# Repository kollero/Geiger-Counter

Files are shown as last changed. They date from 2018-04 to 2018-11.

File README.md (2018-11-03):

# Geiger-counter version 4 C rev

Uses wireless charger so it can be made waterproof. PCB is also narrower and components are more tightly packed. New STL files are needed. 

With 2x sbm-20 tubes, 1.3" Oled display (7pins), Single button on/ (hold) off control (with led), wireless charging,
Atmega328p, only exotic component is mcp73871 (lipo charger IC). 

Display shows time the device has been on (up to 999hours), battery charge after 5 seconds running, 5 second mean of radiation in the middle, current high voltage running to the tubes, and mean value of radiation since the device has been turned on. When detection is made the on/off buttons led is flashed and a chirp is generated. 

5v to 400v boost features IPD90R1k2C3 mosfet, runs at ~22kHz (outside human hearing),
1mH (ELL8TP102MB) inductor is barely enough for this frequency (mainly ESR), also used tantalum capacitors have high ESR, PWM is
PID controlled using atmega328p's 16bit counter.

single ~5000mAh lipo cell, 806090 in size.

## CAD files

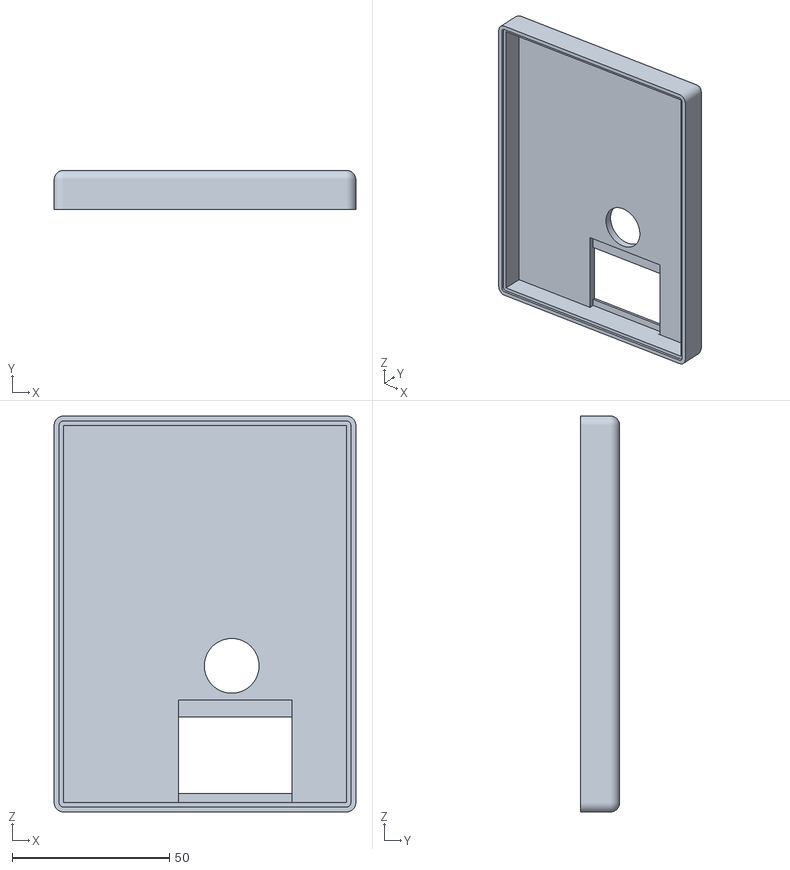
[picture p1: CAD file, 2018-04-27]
STL/1st_gen_top.STL
96.0 x 12.5 x 126.0

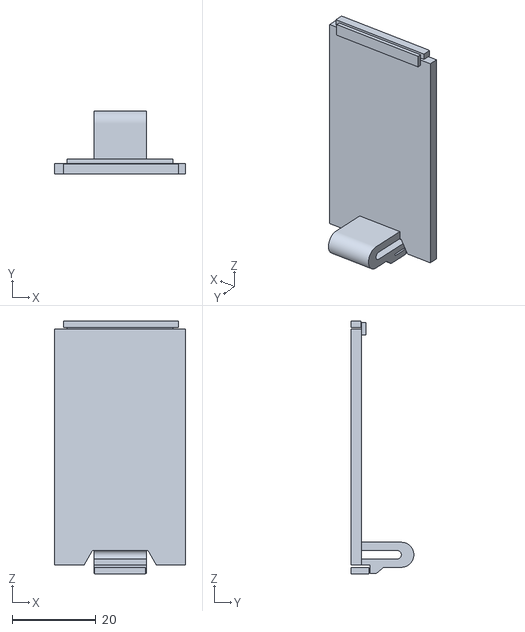
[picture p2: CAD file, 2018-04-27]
STL/cover.STL
31.4 x 15.0 x 60.5

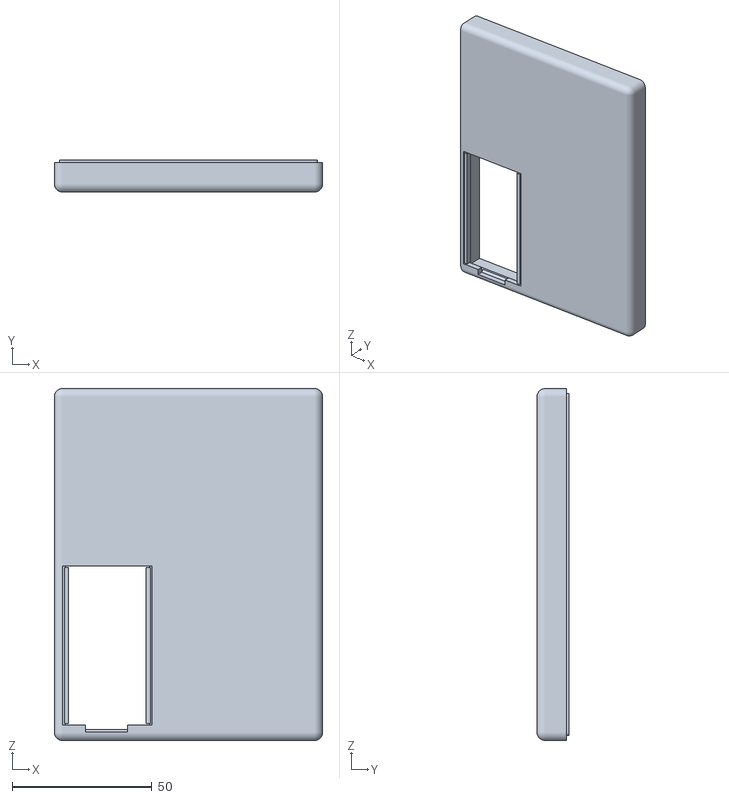
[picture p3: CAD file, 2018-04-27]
STL/1st_gen_bot.STL
96.1 x 11.5 x 126.0

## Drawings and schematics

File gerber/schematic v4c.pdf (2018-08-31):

D

6 | 5 | 4 | 3 | 2 | 1

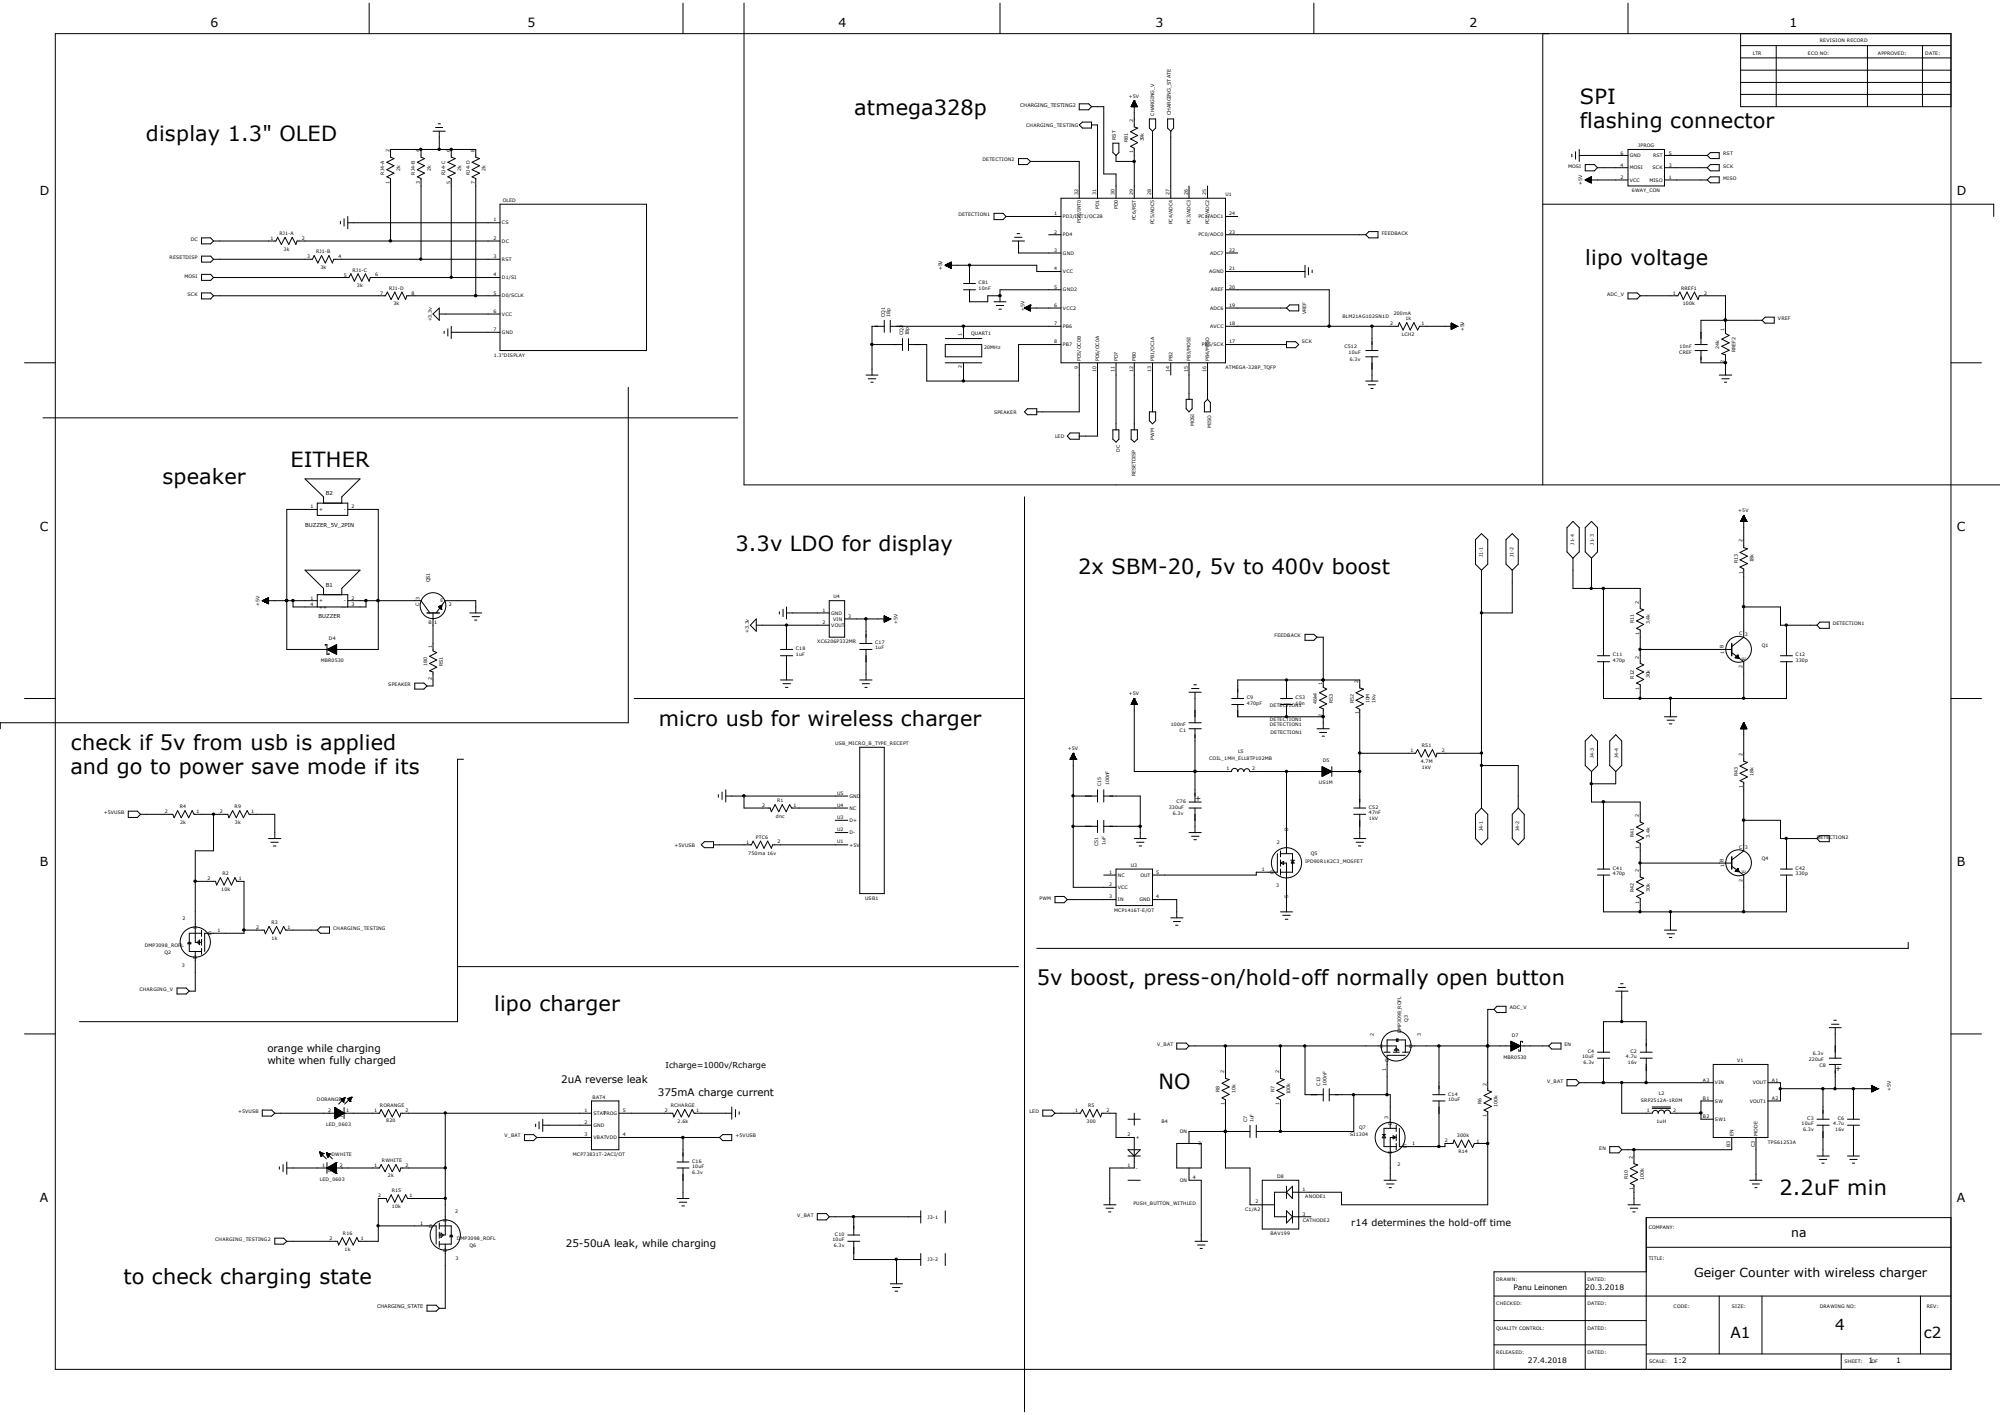
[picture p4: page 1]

display 1.3" OLED | CHARGING_TESTING2 CHARGING_STATE | JPROG | REVISION RECORD

LTR | ECO NO: | APPROVED: | DATE:

24 PC1/ADC1 ²⁵ PC2/ADC2 26 PC3/ADC3 27 PC4/ADC4 28 PC5/ADC5 29 PC6/RST 30 PD⁰ ³¹ PD¹ ³² PD²/INT0

micro usb for wireless charger

check if 5v from usb is applied
and go to power save mode if its

5v boost, press-on/hold-off normally open button

orange while charging
white when fully charged

r14 determines the hold-off time

to check charging state

TITLE:
Geiger Counter with wireless charger

DRAWN: Panu Leinonen | DATED: 20.3.2018
CHECKED: | DATED: | CODE: | SIZE: A1 | DRAWING NO: 4 | REV: c2

QUALITY CONTROL: | DATED:

RELEASED: 27.4.2018 | DATED:

SCALE: 1:2 | SHEET: 1 1 OF

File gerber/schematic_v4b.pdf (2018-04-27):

D

6 | 5 | 4 | 3 | 2 | 1

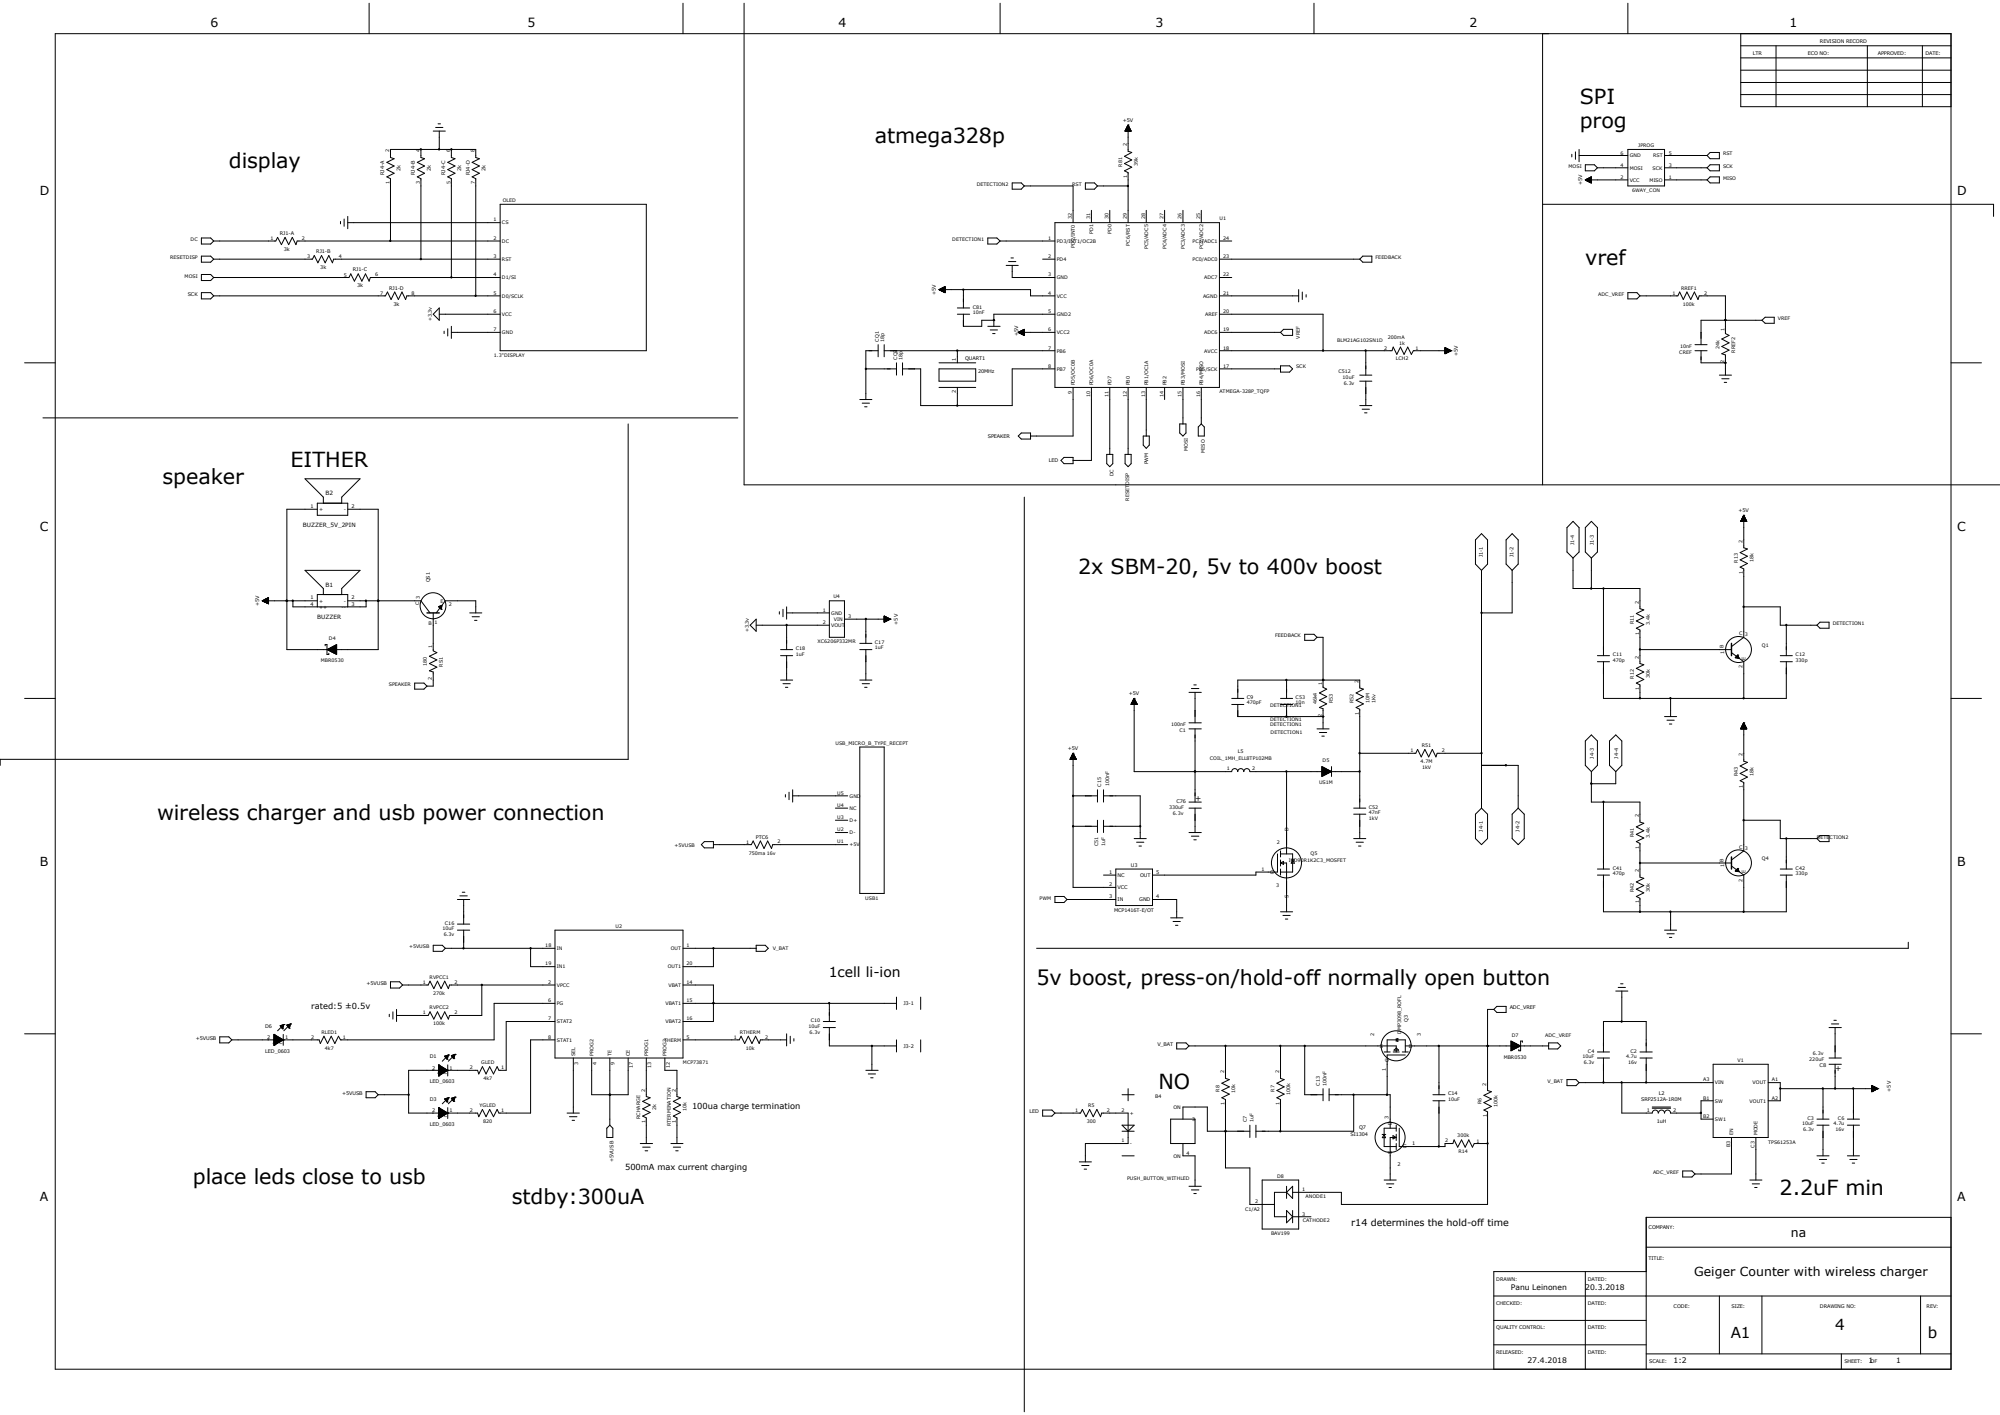
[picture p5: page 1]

DETECTION2 RST | JPROG | REVISION RECORD

LTR | ECO NO: | APPROVED: | DATE:

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

wireless charger and usb power connection

5v boost, press-on/hold-off normally open button

place leds close to usb

r14 determines the hold-off time

Geiger Counter with wireless charger

DRAWN: Panu Leinonen | DATED: 20.3.2018
CHECKED: | DATED: | CODE: | SIZE: A1 | DRAWING NO: 4 | REV: b

QUALITY CONTROL: | DATED:

RELEASED: 27.4.2018 | DATED:

SCALE: 1:2 | SHEET: 1 1 OF

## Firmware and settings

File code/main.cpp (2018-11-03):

/*
 * geigerV14.cpp
 *
 * Created: 20.9.2018 20.53.21
 * Author : kei
 */ 

#define OVERSAMPLING 3
#define I_memory 40 //samples

#define P_val 10
#define I_val 3
#define D_val 6

#include <stdlib.h>
#include <math.h>
#include <stdio.h>
#include <avr/pgmspace.h>
#include <avr/interrupt.h>
#include <avr/wdt.h>
#include <avr/io.h>
#include <util/delay.h>
#include <stdint.h>
#include <stdbool.h>

#include "u8g.h"
u8g_t u8g;



//single sbm-20
double tube1 = 0.344827586207;
//dual sbm-20
double tube2 = 0.172413793104;

double input_voltage_calc = 0.00647; //(10k/8k)*(5v/1024)=0.00610351
double battery_voltage_lvl_calc=0.02576; //(124/24)*(5v/1024)=

//sbm-20 recommended running voltage
double target_voltage=400.0;  //~400v calculated output from resistors


/************************************************************************************************************************************************/
/* Global Objects                                                       																		*/
/************************************************************************************************************************************************/
volatile int32_t    mean_I_err[I_memory],
					PID=0,
					err=0,
					err_old=0,
					mean_I_error=0.0,
					I_err=0.0,
					P_err=0,
					D_err=0;

volatile uint32_t	timer_1s=0,		//these are test counters
					timer_1min=0,
					timer_1h=0,
					geiger_pulse1=0,
					geiger_pulses1=0,
					geiger_pulse2=0,
					geiger_pulses2=0,
					geiger_cps=0,
					geiger_cps2=0,
					total_time_in_seconds=0;

volatile int16_t	duty=0, //initial number
					testing=0,
					fb_voltage=0,
					duty_max=600; 			  //maximum duty cycle/ICR1	39%

volatile uint16_t	timer_seconds=0,	//these house the real time values from when the device was started
					timer_minutes=0,
					timer_hours=0,
					totalnum=0,
					totalnum2=0,
					volt_value=0,
					duty_change_counter=0;
					
volatile bool		first_minute_passed = 0,
					refresh_display=1,
					high_voltage_duty_change=0,
					check_pulses=0,
					v_inputted=0,
					charging=0,
					first_min = 0,
					now=0;
					
bool				cmd_pulse=0,
					setnewhv=0,
					led=0,
					batterylevelcheck=0,
					timernow=0,
					dos_trig_2=0,
					dos_trig=0,
					battery_voltage_check_first_time=1,
					detected_as_broken=0;					
						
uint16_t 			battery_voltage_lvl_ADC=0,
					broken_counter=0;
					
double				actual_cps=0.0,
					actual_cps2=0.0,
					HV_vol=0.0,
					dosage=0.0,
					dosage_1=0.0,
					total_dose=0.0,
					dosage_total=0.0,
					bat=0.0,
					charging_voltage=0.0,
					battery_voltage_lvl= 0.0,	
 					usv=0.0,
					usv_1=0.0,
					actual_cps3=0,
					usv3=0;				
					
uint32_t			totalinmin[60],
					totalinmin2[30];
			
uint16_t xx=120, yy=35, y_start=14;

//chars arrays for printing
char battery[10]={0,0,0,0,0,0,0,0,0,0};	
char secs[10]={0,0,0,0,0,0,0,0,0,0};	
char mins[10]={0,0,0,0,0,0,0,0,0,0};	
char hours[10]={0,0,0,0,0,0,0,0,0,0};	
char usvs[10]={0,0,0,0,0,0,0,0,0,0};	
char HV[10]={0,0,0,0,0,0,0,0,0,0};	
char DOS[10]={0,0,0,0,0,0,0,0,0,0};	
char CHAR_VOLT[10]={0,0,0,0,0,0,0,0,0,0};	
char string_battery_ADC[10]={0,0,0,0,0,0,0,0,0,0};	
char string_bat_percent[10]={0,0,0,0,0,0,0,0,0,0};	

/************************************************************************************************************************************************/
/* Global Objects end                                                       																	*/
/************************************************************************************************************************************************/

#include "lipo.h"
#include "functions.cpp"
#include "pitches.h"
#include "test_sounds.h"

void u8g_setup(void)
{
	
	// SCK: PORTB, Bit 5 --> PN(1,5)
	// MOSI: PORTB, Bit 3 --> PN(1,3)
	// CS: PORTD, Bit 6 --> PN(3,6)
	// A0: PORTD, Bit 7 --> PN(3,7) //DC!!
	// RST: PB0,  --> PN(1,0)
	// Arguments for u8g_InitHWSPI are: CS, A0, Reset
	
	//u8g_InitHWSPI(&u8g, &u8g_dev_ssd1306_128x64_hw_spi, U8G_PIN_NONE,PN(3,7), PN(1,0));
	
	//these work
	u8g_InitHWSPI(&u8g, &u8g_dev_sh1106_128x64_hw_spi,U8G_PIN_NONE,PN(3,7), PN(1,0));
	u8g_SetRot180(&u8g); //flip screen, if required
	
	//u8g_InitHWSPI(&u8g, &u8g_dev_ssd1309_128x64_hw_spi, U8G_PIN_NONE,PN(3,7), U8G_PIN_NONE);
	//u8g_SetRot180(&u8g); //flip screen, if required
	//u8g_SetColorIndex(&u8g, 1);
	
}
void system_setup() {
	
	//pb0=rst disp, pb1 pwm, pb3 mosi, pb5 sck
	DDRB = (1<<PORTB0)|(1<<PORTB1)|(1<<PORTB3)|(1<<PORTB5);
	PORTB =0x01;
	//pc0 feedback
	DDRC =0x00;
	PORTC =0x00;
	//pd1=input v (int),pd2 and pd3 tubes (extint) , pd5 speaker, pd6 led, pd7 dc 
	DDRD = (1<<PORTD5)|(1<<PORTD6)|(1<<PORTD7);
	PORTD =(1<<PORTD6);
	
	//adc set up
	//ADMUX adlar=0, mux 0000 HV-feedback, mux 0110 battery voltage feedback, input V adc5 0101
	ADMUX=(1<<REFS0);
	ADCSRA=(1<<ADEN)|(1<<ADSC)|(1<<ADPS2)|(1<<ADPS1)|(1<<ADPS0); //with 128 clk division
	
	//PWM
	//fast PWM, non-inverting mode set, 16bit timer
	ICR1=800; //@25kHz top
	OCR1A = 0; //initial duty cycle
	TCCR1A = (1<<COM1A1)|(1<<WGM11); //ICR1 selected as top value
	TCCR1B =(1<<WGM13)|(1<<WGM12)|(1<<CS10);
	TIMSK1 =(1<<OCIE1A);

	//external interrupts
	EICRA=(1<<ISC11)|(1<<ISC01); //falling edges on int1 (pd3) and int0 (pd2)
	EIMSK=(1<<INT1)|(1<<INT0); //mask register
	EIFR=(1<<INTF1)|(1<<INTF0); //clear interrupt flags

	//PCint interrupts
	PCICR=(1<<PCIE2)|(1<<PCIE1);
	PCMSK2=(1<<PCINT17); //PD1
	//PCMSK1=(1<<PCINT12); //PC4
	
	//timer 2 control 8 bit
	//output is 20MHz/(256*125)=1.6ms tick
	OCR2A = 124; //runs to value 0:124, to get exact ms
	TCCR2A = (1<<WGM21);
	TCCR2B =(1<<FOC2A)|(1<<CS22)|(1<<CS21); //force compare match A, prescaler to 256
	TIMSK2= (1<<OCIE2A); //masked compare match A
	
	/*
	//chirp or music from timer 0 B output
	OCR0A =255; //max value
	OCR0B=0; //initial duty cycle
	TCCR0A = (1<<COM0B1)|(1<<WGM00); //phase correct  pwm   |(1<<WGM01)
	TCCR0B =(1<<WGM02)|(1<<CS02);// 256 prescaler (must be same as timer 2)
	//TIMSK0=(1<<OCIE0B); //compare match B interrupt
	*/

}



int main(void)
{
	//delay_ms(1000);
	delay_ms(300);
	//zero arrays
	for (int i=0;i< I_memory-1;i++){
		mean_I_err[i]=(int32_t)0.0;
	}
	for (int i = 0; i < 60; i++ ) {
		 totalinmin[i] = 0;
	}
	
	delay_ms(200);
	system_setup();
	u8g_setup();
	//delay_ms(200);
	LCD_clear();
	delay_ms(200);
	
	if(VOLTAGE_APPLIED_PIN){
		v_inputted=1;
		LEDoff;
	}
	/*if(CHARGING_STATE_PIN){
		charging=1;
		LEDoff;
	}*/
	
	//check_battery_voltage();
	
	//cli();
	sei(); //enable interrupts
	
    while (1) 
    {
		if(high_voltage_duty_change){
			high_voltage_duty_change=0;
			high_voltage_duty();
		}
		
		if(check_pulses){
			check_pulses=0;
			/*
			totalinmin[59]=geiger_pulses1+geiger_pulses2; //collisions per second
			
			for (int k = 0; k <= 58; k++)
			{
				totalinmin[k]=totalinmin[k+1];
			}

			for(int k = 59; k >= 0; k--)
			{
				totalnum=totalnum+totalinmin[k];
			}
			*/
			
			
			totalnum+=geiger_pulses1+geiger_pulses2;
			geiger_pulses1=0;
			geiger_pulses2=0;
			
		
			geiger_cps2=totalnum;
			totalnum=0;
			actual_cps2=((geiger_cps2*1000)/(1000-(geiger_cps2*0.190)));
			//total dosage calculation
			dosage_total+=actual_cps2*tube2;
			//174.46 CPM/uSv/hr)-> (cp_total/348.92)((usv/hr)),((c/m)/hr=(1/60)/1)
			//1/(348.92*60)=0.0000477664412091
		
			//dosage=(double)(dosage_total/60);
			//if(first_minute_passed == 0) {
			//	dosage=(double)((dosage_total*60)/timer_seconds);
			//}
			
			total_time_in_seconds=timer_seconds+60*timer_minutes+360*timer_hours;
			dosage=(double)(dosage_total/total_time_in_seconds);
		
			testing++;
			if (testing>=5) //once every 5 seconds
			{
			
				totalnum2=0;
				for(int k = 59; k >= 55; k--)
				{
					totalnum2+=totalinmin[k];	
				}
			
				totalinmin2[29]=totalnum2; //collisions per second
			
				for (int k = 0; k <= 28; k++)
				{
					totalinmin2[k]=totalinmin2[k+1];
				}
			
				geiger_cps=geiger_pulse1+geiger_pulse2; //collisions per second
				actual_cps=(long double)(geiger_cps/(1000-(geiger_cps*0.190)));
				//actual_cps=(float)(geiger_cps/(1-(geiger_cps*0.000190)));
				//190us dead time on SBM-20 before new detection can be made
				//now we have Collisions Per Second as float
				usv=(long double)((tube2*actual_cps)/testing); //174.46 CPM/uSv/hr
				///174.46 CPM/uSv/hr /60)=2.9-> 1/2.9=0.344 usv/hr
				// close to the average of SBM-20, Co60 and Ra226 sensitivity
				// dosage is now in usv/hr (micro)
				//usv=(long double)usv*1000;
				
				if(!detected_as_broken && ((geiger_pulse1 == 0 && geiger_pulse2 !=0) || (geiger_pulse1 != 0 && geiger_pulse2 ==0))){
					broken_counter++;
				}
				else if(!detected_as_broken && geiger_pulse1 !=0 && geiger_pulse2 !=0){
					broken_counter=0;
				}
				if(broken_counter>=10 && !detected_as_broken){
					broken_counter=0;
					//a tube is broken
					tube2=tube1;
					detected_as_broken=1;					
				}
				
				geiger_pulse1=0;			//reset collision counter/
				geiger_pulse2=0;
				testing=0;
				battery_voltage_check_first_time=0;
			}
		}
		if(batterylevelcheck || (battery_voltage_check_first_time && testing>=4))
		{
			check_battery_voltage();
			//bat=(float)0.0255*battery_voltage_lvl; //battery voltage level if resistors have low % tolerances
			//((2.4k+9.91k)/2.4k)*1024/5
			batterylevelcheck=0;
		}
			
		if (led)
		{
			int gah=1;
			int test=15;
			int microtest=90;
			LEDon;
			led=0;
			
			//main chirp
			while(!led && gah <= test){
				BUZon;
				//delay_ms(1);
				//delay_ms(gah);
				delay_us(microtest);
				BUZoff;
				//delay_us(105);
				delay_us(microtest-gah*7);
				gah++;
			}
			gah=1;
			//trailing edge
			while(!led && gah <= test*2){
				BUZon;
				//delay_ms(1);
				//delay_ms(gah);
				delay_us(microtest-gah*8);
				BUZoff;
				//delay_us(105);
				delay_us(microtest);
				gah++;
			}
			LEDoff;
			
		}
		
		if(refresh_display){
			refresh_display=0;
			if(v_inputted){
				LEDoff;
				check_input_voltage();
				check_battery_voltage();
			}
			
			display_draw();
		}
		
    }
}

ISR(TIMER2_COMPA_vect) { //interrupts every 1.6ms
	timer_1s++;
	//zero the timer if 1 second has been reached
	if(timer_1s >= 625)		//625*1.6ms=1s
	{
		timer_seconds++; //increase if under 59 sec
		refresh_display=1; //1 second has passed time to refresh display
		check_pulses=1;
		timer_1s=0;
		if(timer_seconds > 59)
		{
			timer_seconds=0; //zero if
			first_minute_passed=1;
			batterylevelcheck=1;
			timer_minutes++; //increase if under 59 min
			if(timer_minutes > 59)
			{
				timer_minutes=0; //zero if
				timer_hours++;
				if(timer_hours > 998) // no more than 2 digits for hours in display
				{
					timer_hours=0; //zero the timer
				}
				//1hour reached
				timer_1h=0;
			}
			timer_1h++;
		}
	}
}

//high voltage PWM interrupt 
ISR(TIMER1_COMPA_vect){	
	high_voltage_duty_change=1;
	//high_voltage_duty();
}


// external interrupts, falling edges on either
// we have a top limit of 2^32-1 pulses.
ISR (INT0_vect) {
	geiger_pulse1++;
	geiger_pulses1++;
	led=1;
}
ISR (INT1_vect) {
	geiger_pulse2++;
	geiger_pulses2++;
	led=1;
}

//5v applied to charging port
ISR (PCINT2_vect){
	if(VOLTAGE_APPLIED_PIN){
		v_inputted=1;
		battery_voltage_check_first_time=0;
	}
	else{
		v_inputted=0;
		battery_voltage_check_first_time=1;
		testing=0;
	}	
}
/*
//charging
ISR (	PCINT1_vect){
	if(CHARGING_STATE_PIN){
		charging=1;
	}
	else{
		charging=0;
	}
	
	
}*/

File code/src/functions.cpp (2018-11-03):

typedef struct{
	unsigned int bit0:1;
	unsigned int bit1:1;
	unsigned int bit2:1;
	unsigned int bit3:1;
	unsigned int bit4:1;
	unsigned int bit5:1;
	unsigned int bit6:1;
	unsigned int bit7:1;
} _io_reg;
#define REGISTER_BIT(rg,bt) ((volatile _io_reg*)&rg)->bit##bt

#define	LED_PORT REGISTER_BIT(PORTD,6)
#define LEDon LED_PORT = 1
#define LEDoff LED_PORT = 0

#define	SOUND_PORT REGISTER_BIT(PORTD,5)
#define BUZon SOUND_PORT = 1
#define BUZoff SOUND_PORT = 0

#define	CHARGING_STATE_PIN REGISTER_BIT(PINC,4)

#define	VOLTAGE_APPLIED_PIN REGISTER_BIT(PIND,1)

void high_voltage_duty(){
	duty_change_counter++;
	
	if(duty_change_counter >= 100){ //25kHz/100=250Hz
		duty_change_counter=0;
		ADMUX=0b01000000;
		//_delay_us(1);
		volt_value=0;
		fb_voltage=0;
		while(volt_value < OVERSAMPLING){
			ADCSRA |= (1 << ADSC);	 //start an ADC conversion
			while(ADCSRA & _BV(ADSC));    //wait until conversion is complete
			fb_voltage+=ADC;
			volt_value++;
		}
		fb_voltage=round(fb_voltage/OVERSAMPLING);
		HV_vol=(double)1.05*fb_voltage;
		
		// measured 5v actual vcc and resistor values
		//((fb_voltage*5)*((9680000+46.4E3)/46.4E3))/1024=voltage
		//5*209.620689655=0.977
		
		//PID
		err_old=err;
		err=target_voltage-HV_vol;
		P_err=err; //Proportional is directly the difference times P_val (bang bang value)
		
		mean_I_err[I_memory-1]=(int32_t)err;
		mean_I_error=0;
		for (int i=0;i< I_memory-1;i++){
			mean_I_err[i]=(int32_t)mean_I_err[i+1];
			mean_I_error+=(int32_t)mean_I_err[i];
		}
		mean_I_error+=(int32_t)err;
		I_err=(int32_t)mean_I_error;
		D_err=(int32_t)err-err_old;
		
		PID=(int32_t)P_val*P_err + I_val*I_err + D_val*D_err;
		
		
		if( PID > duty_max )
		{
			PID=duty_max;
		}
		else if(PID < 0){
			PID=0;
		}
		
		if(!v_inputted){
			duty=(uint16_t)PID;
			OCR1A=duty; //OCR1A is 16-bit register and now houses the "right" PWM duty cycle for HV
		}
		else{
			OCR1A=0;
			mean_I_error=0;
		}
		
	}
	
}


void check_battery_voltage(){
	//	battery voltage level check at start
		ADMUX=0b01000110; 			  // muxer to battery voltage feedback
		//SMCR |= (1 << SE);
		//SMCR |= (1 << SM0); //adc-noise reduction sleep mode		
		ADCSRA |= (1 << ADSC);
		//ADCSRA |= ADSC;               // start an ADC conversion
		while(ADCSRA & _BV(ADSC));    // wait until conversion is complete
		//ADCSRA |= ADSC;               // start an ADC conversion
		ADCSRA |= (1<<ADSC);
		while(ADCSRA & _BV(ADSC));    // wait until conversion is complete
		//SMCR |= (0 << SE);			//back from sleep
		battery_voltage_lvl_ADC = ADC;    // save the value to battery_voltage_lvl
		ADMUX=0b01000000; 			  // back to HV feedback
		//ADCSRA |= (1<<ADSC);
		//ADCSRA |= ADSC;               // start an ADC conversion
		//while(ADCSRA & _BV(ADSC));    // wait until conversion is complete
		battery_voltage_lvl=(double)battery_voltage_lvl_ADC*battery_voltage_lvl_calc;	
		//batterylevelcheck=1;
}




// reverses a string 'str' of length 'len'
void reverse(char *str, int len)
{
	int i=0, j=len-1, temp;
	while (i<j)
	{
		temp = str[i];
		str[i] = str[j];
		str[j] = temp;
		i++; j--;
	}
}


/*
// Converts a given integer x to string str[].  d is the number
// of digits required in output. If d is more than the number
// of digits in x, then 0s are added at the beginning.
int intToStr(int x, char str[], int d)
{
	int i = 0;
	while (x)
	{
		str[i++] = (x%10) + '0';
		x = x/10;
	}
	
	// If number of digits required is more, then
	// add 0s at the beginning
	while (i < d)
	str[i++] = '0';
	reverse(str, i);	
	str[i] = '\0';
	return i;
}*/


int  intToStr(int x, char str[], int  d)
{
	int  i = 0;
	while (x)
	{
		str[i++] = (x%10) + '0';
		x = x/10;
	}
	
	// If number of digits required is more, then
	// add 0s at the beginning
	while (i < d)
	str[i++] = '0';
	reverse(str, i);
	str[i] = '\0';
	return i;
}



// Converts a floating point number to string.
void ftoad(long double n, char *res, int afterpoint)
{
	// Extract integer part
	int  ipart = (long double)n*1000;
	
	// Extract floating part
	long double fpart =(long double) ((long double)(n*1000) - (long double)ipart);
	
	// convert integer part to string
	//int i = intToStr(ipart, res, 0);
	uint16_t  i = intToStr(ipart, res, 1); //forces to show 0 at the beginning

	// check for display option after point
	if (afterpoint != 0)
	{
		res[i] = '.';  // add dot
		
		// Get the value of fraction part upto given no.
		// of points after dot. The third parameter is needed
		// to handle cases like 233.007
		fpart = fpart* pow(10, afterpoint);
		
		intToStr((int)fpart, res + i + 1, afterpoint);
	}
}

// Converts a floating point number to string.
void ftoa(float n, char *res, int afterpoint)
{
	// Extract integer part
	int ipart = (int)n;
	
	// Extract floating part
	float fpart =(float) (n - (float)ipart);
	
	// convert integer part to string

	//int i = intToStr(ipart, res, 0);

	int i = intToStr(ipart, res, 1); //forces to show 0 at the beginning

	// check for display option after point
	if (afterpoint != 0)
	{
		res[i] = '.';  // add dot
		
		// Get the value of fraction part upto given no.
		// of points after dot. The third parameter is needed
		// to handle cases like 233.007
		fpart = fpart * pow(10, afterpoint);
		
		intToStr((int)fpart, res + i + 1, afterpoint);
	}
}

void delay_us(int us){
	for (int i=0; i < us; i++){
		_delay_us(1);
	}
}

void delay_ms(int ms){
	for (int i=0; i < ms; i++){
		_delay_ms(1);
	}
}	

void LCD_clear(void)
{	
	u8g_SetDefaultBackgroundColor(&u8g);
	u8g_DrawBox(&u8g,0,0,132,64); //clears the screen
	u8g_SetDefaultForegroundColor(&u8g);
	u8g_SetFont(&u8g, u8g_font_6x10);
	//u8g_DrawBox(&u8g, 5,10,20,10);
	
}

#define battery_x_offset 7

void battery_full_marking(void)
{
	u8g_SetFont(&u8g, u8g_font_7x13);
	u8g_DrawBox(&u8g,66+battery_x_offset,7,2,3);
	u8g_DrawBox(&u8g,68+battery_x_offset,5,11,7);      
}

void battery_80_90_marking(void)
{
	u8g_SetFont(&u8g, u8g_font_7x13);
	u8g_DrawBox(&u8g,66+battery_x_offset,7,2,3);
	u8g_DrawFrame(&u8g,68+battery_x_offset,5,11,7);      
	u8g_DrawBox(&u8g,70+battery_x_offset,5,8,7);
}
void battery_70_80_marking(void)
{
	u8g_SetFont(&u8g, u8g_font_7x13);
	u8g_DrawBox(&u8g,66+battery_x_offset,7,2,3);
	u8g_DrawFrame(&u8g,68+battery_x_offset,5,11,7);      
	u8g_DrawBox(&u8g,71+battery_x_offset,5,7,7);
}
void battery_60_70_marking(void)
{
	u8g_SetFont(&u8g, u8g_font_7x13);
	u8g_DrawBox(&u8g,66+battery_x_offset,7,2,3);
	u8g_DrawFrame(&u8g,68+battery_x_offset,5,11,7);      
	u8g_DrawBox(&u8g,72+battery_x_offset,5,6,7);
}

void battery_50_60_marking(void)
{
	u8g_SetFont(&u8g, u8g_font_7x13);
	u8g_DrawBox(&u8g,66+battery_x_offset,7,2,3);
	u8g_DrawFrame(&u8g,68+battery_x_offset,5,11,7);      
	u8g_DrawBox(&u8g,73+battery_x_offset,5,5,7);
}

void battery_40_50_marking(void)
{
	u8g_SetFont(&u8g, u8g_font_7x13);
	u8g_DrawBox(&u8g,66+battery_x_offset,7,2,3);
	u8g_DrawFrame(&u8g,68+battery_x_offset,5,11,7);      
	u8g_DrawBox(&u8g,74+battery_x_offset,5,4,7);
}
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
